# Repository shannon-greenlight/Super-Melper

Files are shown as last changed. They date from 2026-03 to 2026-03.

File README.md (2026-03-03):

# The Super Melper
The Super Melper converts a Moog case into a powered Eurorack case.

It requires +12V as an input and generates two -12V each powering 6 of the connectors and +5V that powers all twelve connectors.
Three LEDs monitor the supply rails.
It is targeted to Moog cases, but can be used in any case that has +12V.
The 12 volt wall wart that Moog supplies works well. 

This repo contains the schematic and layout files needed to create the Super Melper.
These files are for KiCAD Version: 8.0.8

The repo also contains the BOM files that are used to buy the components.
These are found in the _BOM_ folder.
The BOM files for DigiKey and JLCPCB are provided in .csv format.
Other suppliers typically will accept these files with minor modifications.

The repo also contains the files needed for fabrication. These are found in the _fab_ folder.
These include the gerber files, which are provided both as a zip file and as the full unzipped folder structure.
Also included in the _fab_ folder are the files needed for pick-and-place.
The .xlsx file is the pick-and-place file. It is formatted for JLCPCB.
The raw position files are found in the _pos_ folder.

# Specs
The Super Melper derives two -12V outputs and +5V from the +12V supply.
- +12V Input
	- Range: +11.5V thru +12.5V
	- Minimum Current: 1A
- -12V Outputs
	- Voltage range: -11.75V thru -12.25V
	- Maximum current: 250mA each output
	- Effeciency: 66% typ.
	- Line regulation: 15mV
	- Load regulation: 20mV
	- Ripple: 230mV
- +5V Output
	- Voltage range: +4.8V thru +5.2V
	- Maximum current: 500mA
	- Line regulation: 3mV typ.
	- Load regulation: 10mV typ.
	- Ripple rejection: 80dB typ.

# Making Changes
The process of making changes usually starts with altering the schematic followed by other actions as required.
This requires a properly configured KiCAD installation. Download the KiCAD [repo](https://github.com/shannon-greenlight/KiCAD) and follow the instructions in the README to install.
When the system is configured follow the steps outlined below. Some steps are optional depending on what has changed.

These procedures have been optimized for use with Digi-Key and JLCPCB. They should be a good starting point for use with other vendors.

- Update schematic
	- Update revision in File->Page Settings
	- Plot pdf version of schematic.
- If any parts have changed, Update BOMs
	- From KiCAD Schematic Editor, run Tools->Generate Legacy Bill of Materials using bom2grouped_csv.xsl
		- bom2grouped_csv.xsl is found in the Greenface KiCAD repo.
		- Here is a sample command line: xsltproc -o "%O.csv" "C:\Users\shann\Dropbox\KiCAD\bom2grouped_csv.xsl" "%I"
		- This creates a .csv and an xml file. The xml file is used in the next step.
	- Run _generate_boms.bat_
		- This creates 3 .csv files
			- BOM\Digi-Key\SuperMelper_full.csv (all components)
			- BOM\Digi-Key\SuperMelper_split.csv (just components not found in LCSC BOM)
			- BOM\LCSC\SuperMelper_bom.csv (just components to be assembled by JLCPCB)
		- generate_boms.bat requires Python and the Greenface Python [libraries](https://github.com/shannon-greenlight/PYTHON_BOM) to be installed
			- Place the Greenface Python folder in a convienient place on your computer and set the variable %plugin_dir% to point to that folder location.
			- Python is invoked as 'py' in the batch file. This may need to be changed depending on your Python installation.
- Update layout if required
	- Update revision in File->Page Settings
	- Plot the Gerber files
		- Set the output directory to _fab\gerber\\_
		- Make sure to Generate Drill Files
		- Create a zip archive of the Gerber files. (This is required by JLCPCB)
			- Use Windows Send To Compressed Folder. Rename the resulting file to super_melper_gerbers.zip
			- Alternatively, use zip_gerbers.bat
			- zip_gerbers.bat requires 7z.exe
			- Edit this file if 7z.exe is installed somewhere other than C:\Program Files\7-Zip
	- Create the pick-and-place files
		- From KiCAD PCB Editor, run File->Fabrication Outputs->Component Placement
		- Set the output directory to _fab\pos\\_
		- This creates the files used by the next step
		- Update position_cpl.xlsx
			- position_cpl.xlsx uses Excel Queries to convert pos\SuperMelper-top-pos.csv into a format compatible with JLCPCB
			- Excel requires an absolute path to the source folder of the data. Edit the query to enter the path to your project.
			- *note: This process does not produce a perfect placement file due to differences in how KiCAD and JLCPCB orient components. However, JLCPCB is able to use the file without problems. So, even if the placement looks wrong when specifying the build, they will use the file and produce correct boards.
			- **note: There is probably a KiCAD plugin available that does a better job. The user is encouraged to try this route and report the results back.
- Upload to JLCPCB
	- JLCPCB requires the following files:
		- fab\super_melper_gerbers.zip
		- fab\super_melper_cpl.xlsx (only needed for assembly)
		- bom\LCSC\SuperMelper_bom.csv (only needed for assembly)

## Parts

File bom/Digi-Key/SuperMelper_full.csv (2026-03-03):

Reference | Quantity | Value | Digi-Key Part #
C1, C5, C9, C10, C14, C17, | 6 | 100uF | P15436CT-ND
C2, C4, C16, | 3 | .1uF | 311-1344-1-ND
C3, C6, C11, | 3 | 330pF | 1276-1073-1-ND
C7, | 1 | 10uF | 490-18214-1-ND
C8, C12, C13, C15, | 4 | 1000uF | 10-EEH-ZS1E102UPCT-ND
D1, D2, D6, | 3 | 1N5819 | 1N5819HW-FDICT-ND
J1, J2, J3, J4, J5, J6, J7, J8, J9, J10, J11, J12, | 12 | Conn_02x08_Odd_Even | S9171-ND
J13, J14, J17, J18, | 4 | Conn_01x02 | SAM10844-ND
L1, L2, L6, | 3 | 100uH | 541-IFDC5050HZER101MCT-ND
L3, L4, L5, | 3 | 1.8uH | 445-3181-1-ND
LED1, | 1 | Red SMT LED | 160-1436-1-ND
LED2, | 1 | Yellow SMT LED | 160-1437-1-ND
LED3, LED4, | 2 | Blue SMT LED | 160-1837-1-ND
R1, R3, R13, | 3 | 10K | 311-10.0KHRCT-ND
R2, | 1 | 4.7K | 311-4.70KHRCT-ND
R4, R8, R11, | 3 | 1K | 311-1.00KHRCT-ND
R5, R12, | 2 | 8.66K | 311-8.66KHRCT-ND
R6, R7, R10, | 3 | .33 | 273-KDV06FR330ETCT-ND
R9, | 1 | 3K | 311-3.00KHRCT-ND
TP1, | 1 | TestPoint | 36-5006-ND
U1, U2, U3, | 3 | MC34063AD | MC34063ADR2GOSCT-ND

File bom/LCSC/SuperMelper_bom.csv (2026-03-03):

Designator | Comment | Footprint | JLCPCBPart#
C1, C5, C9, C10, C14, C17, | 100uF | Capacitor_SMD:CP_Elec_6.3x5.4_Nichicon | C264047
C2, C4, C16, | .1uF | Capacitor_SMD:C_0603_1608Metric | C14663
C3, C6, C11, | 330pF | Capacitor_SMD:C_0603_1608Metric | C1664
C7, | 10uF | Capacitor_SMD:C_0603_1608Metric | C344022
C8, C12, C13, C15, | 1000uF | Capacitor_SMD:CP_Elec_10x12.6 | C6547400
D1, D2, D6, | 1N5819 | Diode_SMD:D_SOD-123 | C82544
J1, J2, J3, J4, J5, J6, J7, J8, J9, J10, J11, J12, | Conn_02x08_Odd_Even | greenface:PinHeaderShrouded_2x08_P2.54mm_Vertical | C7430313
J13, J14, J17, J18, | Conn_01x02 | Connector_PinHeader_2.54mm:PinHeader_1x02_P2.54mm_Vertical | C492401
L1, L2, L6, | 100uH | Inductor_SMD:L_SXN_SMDRI127 | C10150
L3, L4, L5, | 1.8uH | Inductor_SMD:L_Sunlord_SWPA4012S | C96867
LED1, | Red SMT LED | LED_SMD:LED_0603_1608Metric_Pad1.05x0.95mm_HandSolder | C2286
LED2, | Yellow SMT LED | LED_SMD:LED_0603_1608Metric_Pad1.05x0.95mm_HandSolder | C72038
LED3, LED4, | Blue SMT LED | LED_SMD:LED_0603_1608Metric_Pad1.05x0.95mm_HandSolder | C2288
R1, R3, R13, | 10K | Resistor_SMD:R_0603_1608Metric | C25804
R2, | 4.7K | Resistor_SMD:R_0603_1608Metric | C23162
R4, R8, R11, | 1K | Resistor_SMD:R_0603_1608Metric | C21190
R5, R12, | 8.66K | Resistor_SMD:R_0603_1608Metric | C3000724
R6, R7, R10, | .33 | Resistor_SMD:R_0603_1608Metric | C4321766
R9, | 3K | Resistor_SMD:R_0603_1608Metric | C4211
TP1, | TestPoint | TestPoint:TestPoint_Keystone_5005-5009_Compact | C238122
U1, U2, U3, | MC34063AD | Package_SO:SOIC-8-1EP_3.9x4.9mm_P1.27mm_EP2.41x3.3mm_ThermalVias | C32078

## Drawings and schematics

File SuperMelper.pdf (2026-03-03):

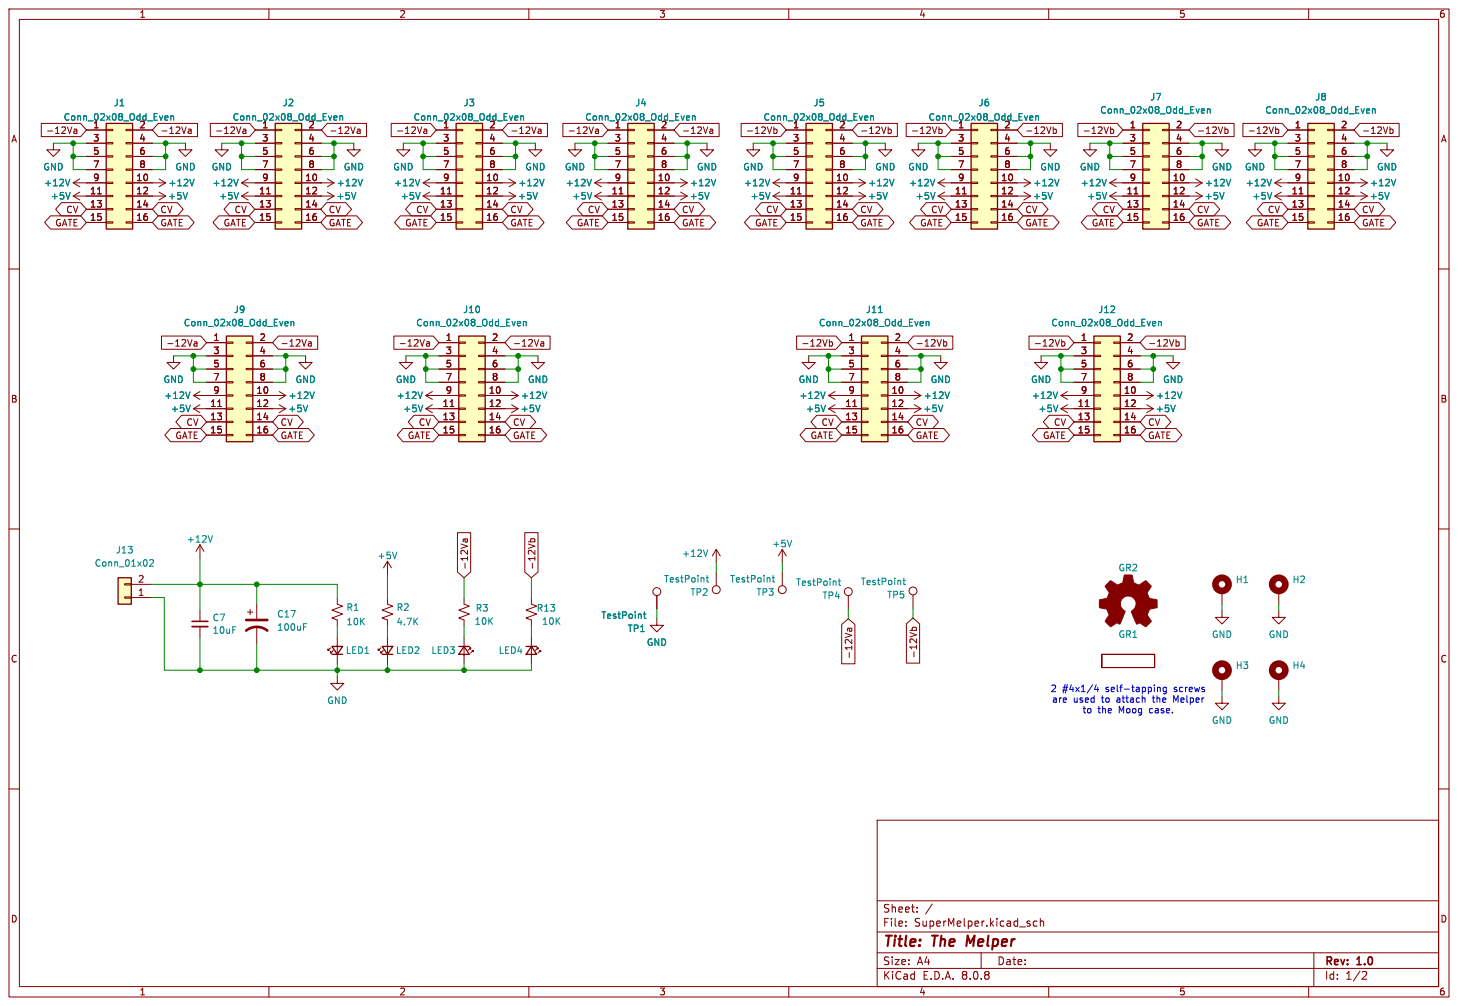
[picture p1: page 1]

to the Moog case.

Id: 1/2 Title: The Melper File: SuperMelper.kicad_sch Sheet: /

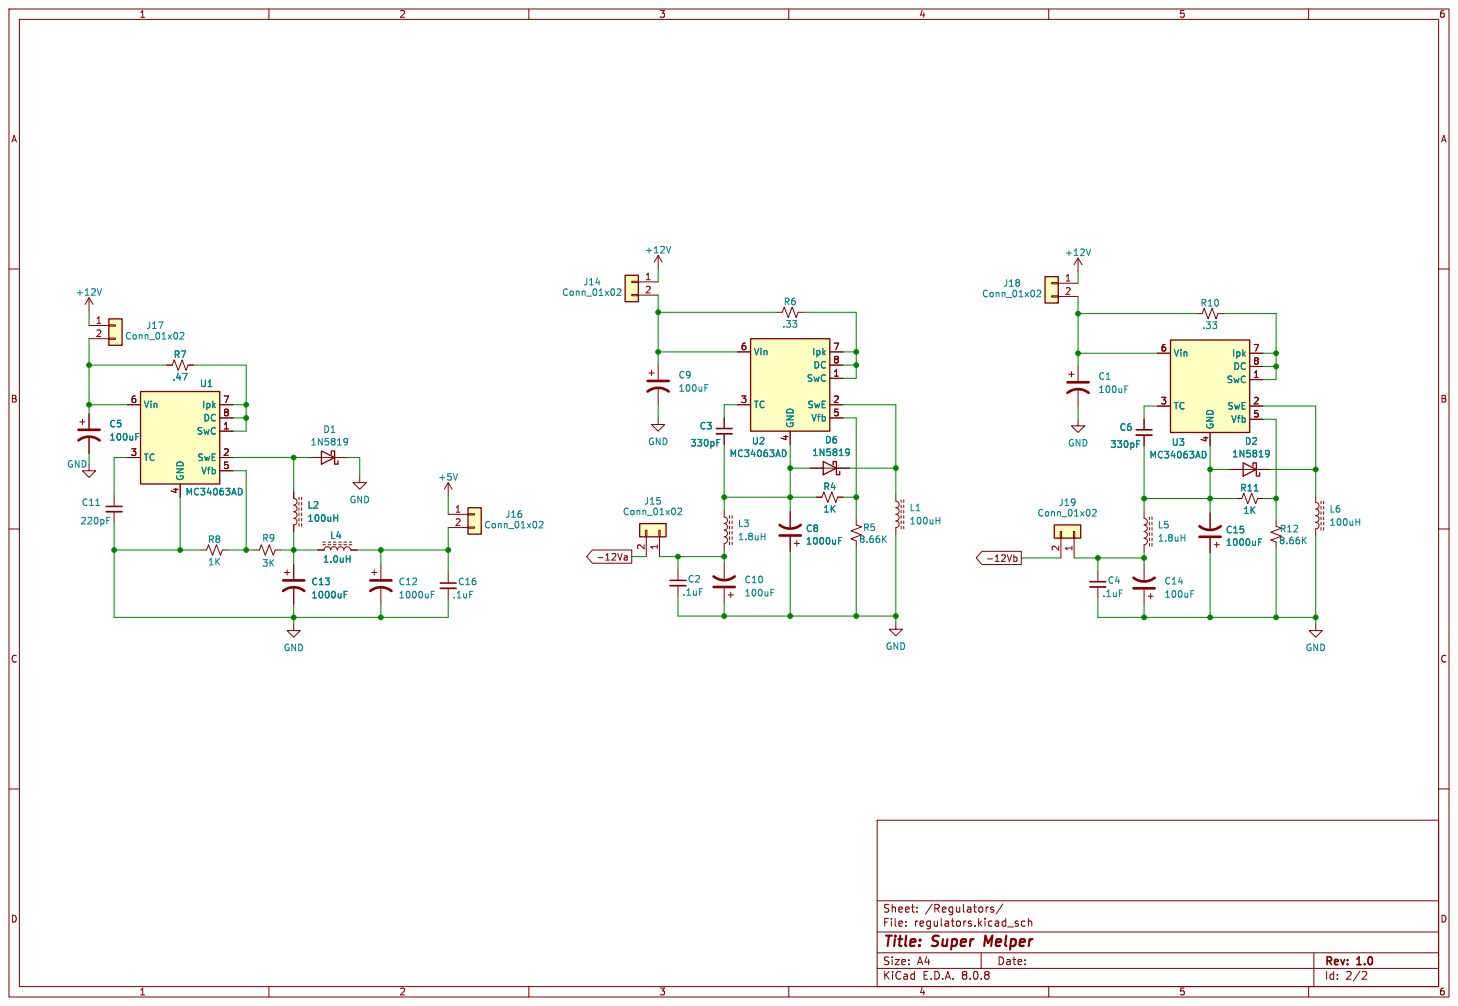
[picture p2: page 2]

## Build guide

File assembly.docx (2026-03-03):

# Melper Assembly Instructions

Skill Level – Beginner

### OK for 1st build if practiced beforehand – see Tips section

Please read this entire document before starting the build.

# Tools and Materials

- The documents: GitHub Repo (https://github.com/shannon-greenlight/Melper)
  - The schematic: Melper.pdf
  - The BOM (bill of materials): bom\Digi-Key\Melper_full.csv
- The Melper:
  - The revision of the board should match the revision of the schematic.
  - The schematic revision is located in the lower right corner of the schematic.
- Components: Verify that you have all the components specified in the BOM.
  - Note that the LEDs and the 1.8uH inductor are specified twice in the BOM. Choose one or the other depending on availability. The through-hole versions of the parts are preferred. Refer to the schematic for more details.
- Soldering Iron and Solder:
  - A fine-tipped soldering iron A .8mm conical tip is suggested.
  - Use rosin-core solder.
  - .8mm diameter solder is good for through hole work such as the Melper.
  - Lead-based solder has increased health risks but is much easier to use.
- Solder braid and or solder sucker (in case of mistakes).
- Diagonal cutters and Needle-Nose Pliers: Make sure to use tools that are designed for circuit assembly.
  - We like Hakko tools for electronics work.
  - A lead-bending tool is not required but is very helpful. This one (https://www.amazon.com/SplashNColor-Precision-Resistor-Lead-Bender/dp/B0D3YBHDZQ) looks like it would work.
- Multimeter: Use to verify the three voltage rails and to troubleshoot.
- A solder fume extractor is recommended. A fan to suck the fumes away from the work area is better than nothing if an extractor isn’t available.
- Circuit vise: Optional, but highly recommended. Example - Velleman VTHH6-VP on Amazon (https://www.amazon.com/Velleman-VTHH6-VP-Circuit-Board-Clamping/dp/B06WD69MG1)
- Magnifying Glass: Helps inspect solder joints and components.

# Assembly

Note that both reference designators and component values are printed on the circuit board. This greatly reduces the risk of misplacing components.

It pays to double-check the component placement before soldering.

You’ll need to position the clamp in various places on the circuit board to make room for soldering. The image below shows that the board is positioned for soldering the Eurorack power connectors.

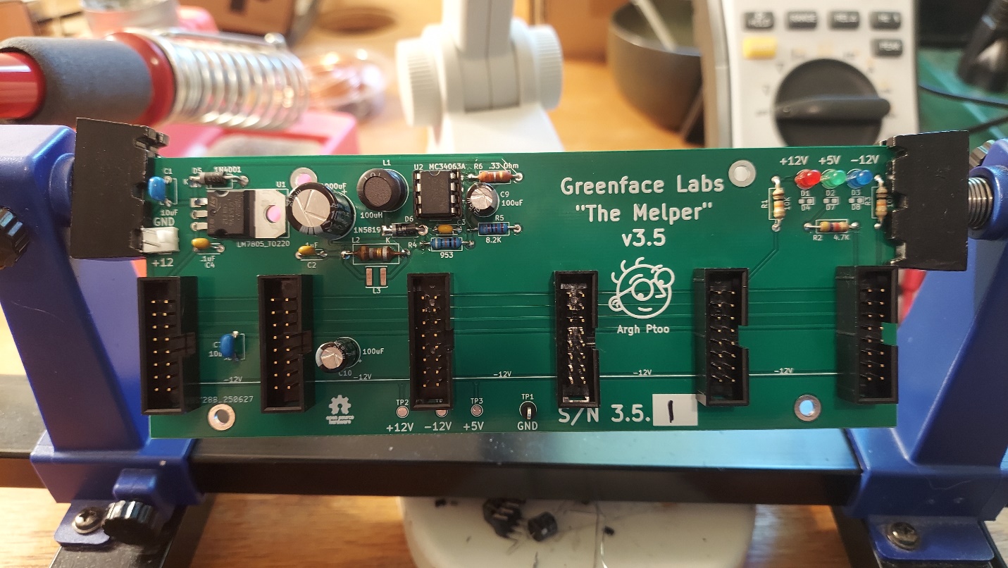
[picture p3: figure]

We feel it is best practice to leave component leads going straight through the board rather than bending them. This makes it much easier to remove components if rework is required later. Several techniques can be used to hold the component in place while soldering depending on the component. If you are unsure about this, using a practice soldering board is recommended.

# Testing

- Visual Inspection: Examine the Melper for misplaced components, cold solder joints or solder bridges.
- Electrical Testing: Use a multimeter to verify the three voltage rails. The test points make measuring easier.
  - Apply +12V power source to the input connector, J7.
  - Verify that all three power monitor LEDs are on.
  - +12V should remain within specs for the source used
  - -12V and +5V should be within the voltage range indicated in the specs that are published on the Melper web page.
- Functional Testing:
  - Put one of your modules in your new case and try it out.
    - Make sure this module does not require more current than the Melper can supply.
  - If the module doesn’t work try swapping modules and double-checking everything.
  - A complete troubleshooting guide is beyond the scope of this document. If you need help please Contact - Greenface Labs (https://www.greenfacelabs.com/contact/).

# Tips and Best Practices

- Work in a clean, well-lit, well-ventilated area.
- Wear eye-safety gear, such as goggles, when soldering and trimming leads to protect yourself from sputtering/splashing solder and flying bits of metal.
- If this is one of your first builds, practice soldering on a spare board or dedicated practice board to improve your technique before starting the Melper assembly.
  - This kit from Amazon looks good and cheap: Soldering Practice Kit (https://www.amazon.com/dp/B0CW9RWRTT?sp_csd=d2lkZ2V0TmFtZT1zcF9kZXRhaWxfdGhlbWF0aWM)
- Keep a “measure twice, cut once” attitude.
- Always prefer the best results over the quickest results. (harder than it sounds!)

# Disclaimer

The above text is our best recommendations for safely building a functional product. Greenface Labs cannot guarantee or be held liable for the safety of the builder or the success of the project based on these recommendations.

We also understand that much of this may be daunting to the beginner who is starting with little or no equipment. However, the Melper can be successfully built using just a soldering iron and a cutter to trim the leads. If the lights light up, then it probably works.
